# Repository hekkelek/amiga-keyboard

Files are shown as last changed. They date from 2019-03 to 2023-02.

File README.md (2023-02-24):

# Mechanical Replacement Keyboard for Amiga 500 and 1200

Many years ago I got an Amiga 500 with missing keyboard. Since then original keyboards became so expensive, that custom mechanical keyboards can be built for the price of an original.
Unfortunately, Amiga-style Cherry MX keycaps are unavailable, so I used DSA profile blank keycaps. As 9 unit space is rare, I used a 7 unit instead.

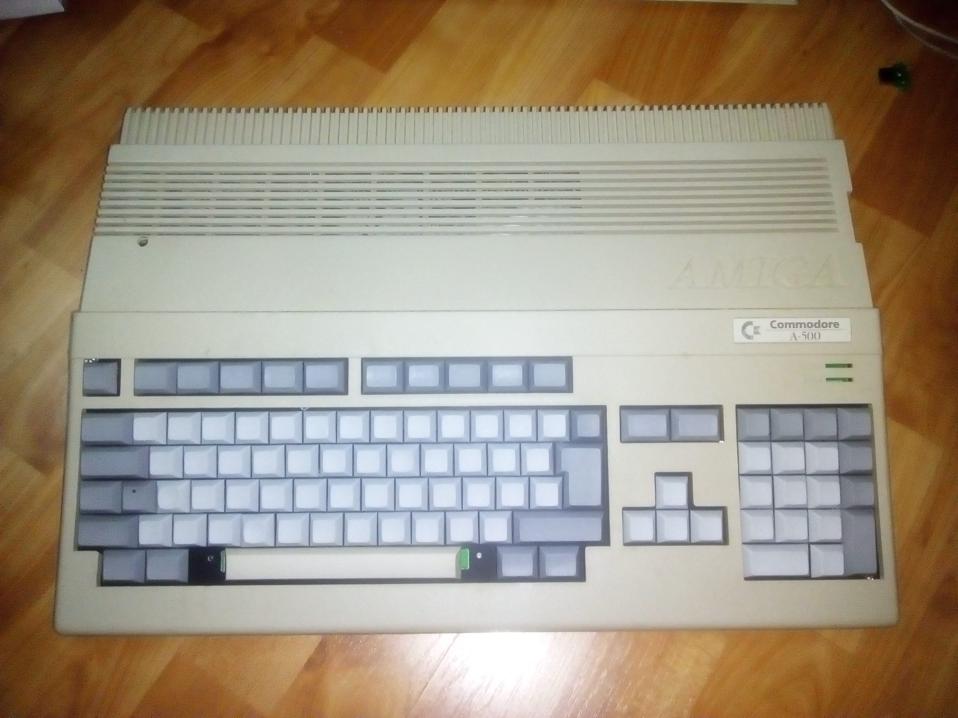
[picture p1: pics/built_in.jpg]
finished


## How to build
First, order the PCB from your favourite manufacturer using the Gerber files in /hw/fab/. At the same time, get a 1.5 mm thick plate, paint it black, and mill out the support plate using a CNC mill. You can find the design files in DXP and Gerber format in /hw/fab/. 
After you got the PCB, populate the connector to the motherboard, and all the SMD components on the top layer. Then, using screws and nuts/washers fasten the support plate to the PCB. Don't forget to add the brackets to larger keys such as space. Only at this point you should solder the key switches. Populate the diodes at the bottom layer. And finally, using an ST-Link v2 programmer, you can burn the hex file in /fw/release/ to the microcontroller.

## Known bugs

Revision A was a failure, as the position of many keys was inaccurate. Revision B seems good so far -- maybe a little bit of fileing needed here and there, for the best fit. Also, the positions of the LEDs are not accurate for the original LEDs.

The firmware is not finished yet -- it works for most of the time, but it's not perfect.

## Tools used

* Altium Designer 2011
* IAR Embedded Workbench for STM8 1.40.1

## Some more pictures
The PCB:
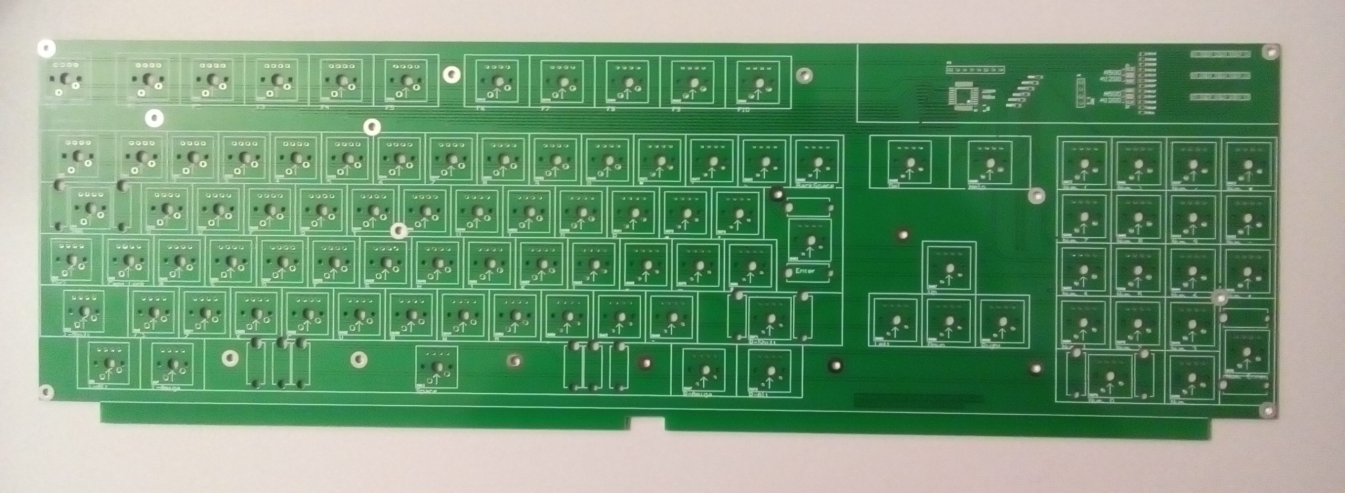
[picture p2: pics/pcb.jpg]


Assembled (note: an additional hole was cut on the plate to debug the MCU):
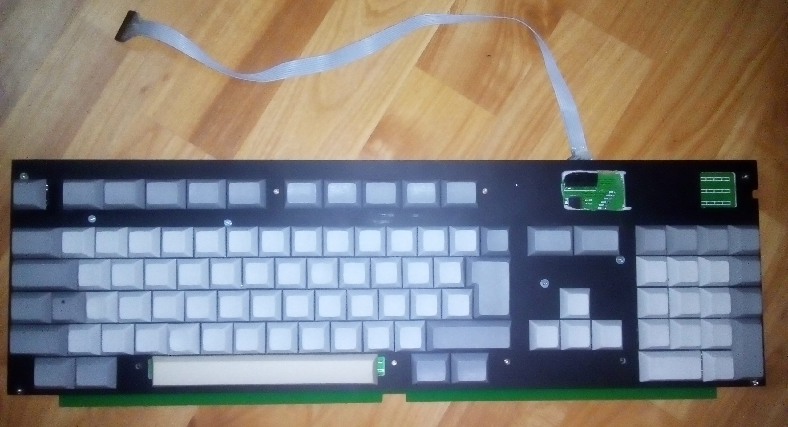
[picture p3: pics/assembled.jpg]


Original Amiga profile keycaps:
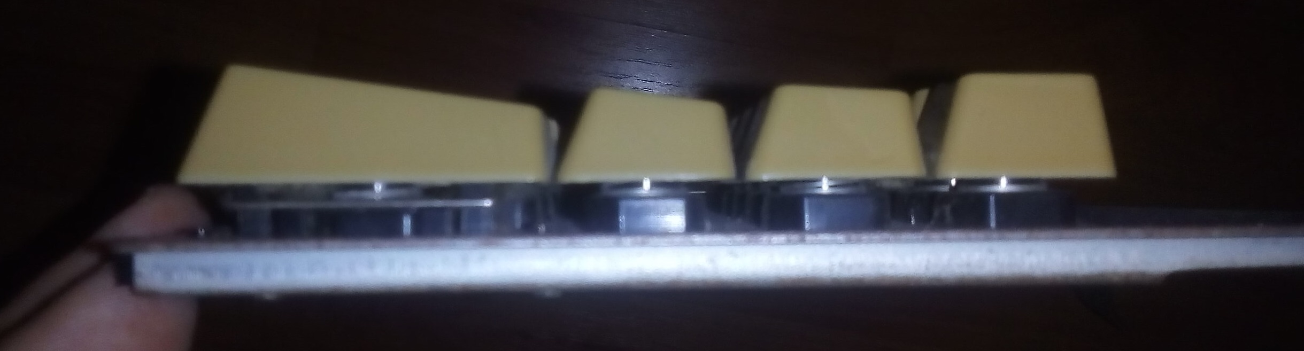
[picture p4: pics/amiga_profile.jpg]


DSA profile keycaps:
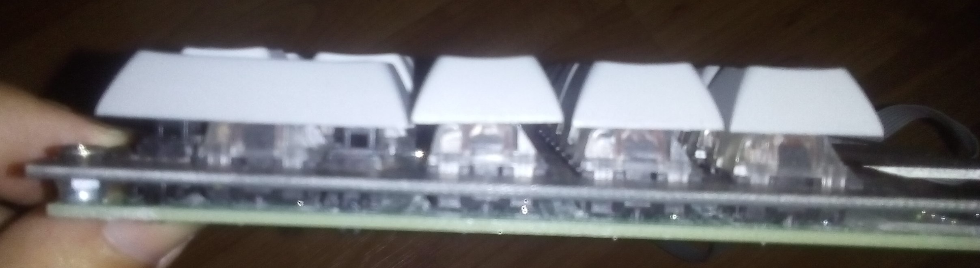
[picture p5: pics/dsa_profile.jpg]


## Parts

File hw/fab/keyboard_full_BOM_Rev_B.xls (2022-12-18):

Designator | Value | Comment | Description | Footprint | Quantity
C1 | 1uF | 0805 | Capacitor SMD Cer X7R 0805 | CAPC2012X135N | 1
C2 | 100nF | 0805 | Capacitor SMD Cer X7R 0805 | CAPC2012X135N | 1
D1, D4, D7, D10 |  | GREEN | Typical LED | LEDSQ_5mm | 4
D2, D3, D5, D6, D8, D9, D11, D12 |  | YELLOW | Typical LED | LEDSQ_5mm | 8
D13, D14, D15, D16, D17, D18, D19, D20, D21, D22, D23, D24, D25, D26, D27, D28, D29, D30, D31, D32, D33, D34, D35, D36, D37, D38, D39, D40, D41, D42, D43, D44, D45, D46, D47, D48, D49, D50, D51, D52, D53, D54, D55, D56, D57, D58, D59, D60, D61, D62, D63, D64, D65, D66, D67, D68, D69, D70, D71, D72, D73, D74, D75, D76, D77, D78, D79, D80, D81, D82, D83, D84, D85, D86, D87, D88, D89, D90, D91, D92, D93, D94, D95, D96, D97, D98, D99, D100, D101, D102, D103, D104, D105, D106, D107, D108 | Vf=1V @ 10mA | Mini MELF | Diode SMD 100V 150mA 500mW SOD80 | SOD80, LL-34 | 96
P1 |  | SWIM | Header, 4-Pin | HDR1X4 | 1
P2 |  | Amiga Keyboard | Header, 8-Pin | HDR1X8 | 1
R1, R2, R3, R4, R5, R6, R7, R8, R10, R11, R12, R13, R14, R15, R16, R17, R18, R19, R20, R21, R22, R23, R24, R25, R26, R27, R28, R29, R30, R31, R32, R33, R34, R35, R36, R37, R38, R39, R40, R41, R42, R43, R44, R45, R46, R47, R48, R49, R50, R51, R52, R53, R54, R55, R56, R57, R58, R59, R60, R61, R62, R63, R64, R65, R66, R67, R68, R69, R70, R71, R72, R73, R74, R75, R76, R77, R78, R79, R80, R81, R82, R83, R84, R85, R86, R87, R88, R89, R90, R91, R92, R93, R94, R95, R96 | Opc. | 0805 | Resistor SMD chip 0.0 Ohm 0.125W 0805 | RESC2012N_ZERO | 95
R9, R97 | 1k | 0805 | Resistor SMD chip 0.0 Ohm 0.125W 0805 | RESC2012N_ZERO | 2
R98, R99, R100, R101, R102, R103 | 4,7k | 0805 | Resistor SMD chip 0.0 Ohm 0.125W 0805 | RESC2012N_ZERO | 6
R104, R105, R106, R107, R108, R109, R110, R111, R112, R113, R114, R115 | TBD | 0805 | Resistor SMD chip 0.0 Ohm 0.125W 0805 | RESC2012N_ZERO | 12
ST1, ST2, ST3, ST4, ST5, ST6, ST7, ST8, ST9, ST10, ST11, ST12, ST13, ST14, ST15, ST16 |  | Cherry MX Stabilizer | Stabilizer for Cherry MX compatible switches | CHERRYMX_STAB | 16
SW1 |  | L-Alt | Cherry MX keyboard switch | CHERRYMX_5PIN | 1
SW2 |  | L-Shift | Cherry MX keyboard switch | CHERRYMX_5PIN | 1
SW3 |  | Ctrl | Cherry MX keyboard switch | CHERRYMX_5PIN | 1
SW4 |  | TAB | Cherry MX keyboard switch | CHERRYMX_5PIN | 1
SW5 |  | ~ | Cherry MX keyboard switch | CHERRYMX_5PIN | 1
SW6 |  | ESC | Cherry MX keyboard switch | CHERRYMX_5PIN | 1
SW7 |  | L-Amiga | Cherry MX keyboard switch | CHERRYMX_5PIN | 1
SW8 |  | < > | Cherry MX keyboard switch | CHERRYMX_5PIN | 1
SW9 |  | Caps Lock | Cherry MX keyboard switch | CHERRYMX_5PIN | 1
SW10 |  | Q | Cherry MX keyboard switch | CHERRYMX_5PIN | 1
SW11 |  | 1 | Cherry MX keyboard switch | CHERRYMX_5PIN | 1
SW12 |  | F1 | Cherry MX keyboard switch | CHERRYMX_5PIN | 1
SW13 |  | Space | Cherry MX keyboard switch | CHERRYMX_5PIN | 1
SW14 |  | Z | Cherry MX keyboard switch | CHERRYMX_5PIN | 1
SW15 |  | A | Cherry MX keyboard switch | CHERRYMX_5PIN | 1
SW16 |  | W | Cherry MX keyboard switch | CHERRYMX_5PIN | 1
SW17 |  | 2 | Cherry MX keyboard switch | CHERRYMX_5PIN | 1
SW18 |  | F2 | Cherry MX keyboard switch | CHERRYMX_5PIN | 1
SW19 |  | Num. * | Cherry MX keyboard switch | CHERRYMX_5PIN | 1
SW20 |  | X | Cherry MX keyboard switch | CHERRYMX_5PIN | 1
SW21 |  | S | Cherry MX keyboard switch | CHERRYMX_5PIN | 1
SW22 |  | E | Cherry MX keyboard switch | CHERRYMX_5PIN | 1
SW23 |  | 3 | Cherry MX keyboard switch | CHERRYMX_5PIN | 1
SW24 |  | F3 | Cherry MX keyboard switch | CHERRYMX_5PIN | 1
SW25 |  | Num. - | Cherry MX keyboard switch | CHERRYMX_5PIN | 1
SW26 |  | C | Cherry MX keyboard switch | CHERRYMX_5PIN | 1
SW27 |  | D | Cherry MX keyboard switch | CHERRYMX_5PIN | 1
SW28 |  | R | Cherry MX keyboard switch | CHERRYMX_5PIN | 1
SW29 |  | 4 | Cherry MX keyboard switch | CHERRYMX_5PIN | 1
SW30 |  | F4 | Cherry MX keyboard switch | CHERRYMX_5PIN | 1
SW31 |  | Num. Enter | Cherry MX keyboard switch | CHERRYMX_5PIN | 1
SW32 |  | V | Cherry MX keyboard switch | CHERRYMX_5PIN | 1
SW33 |  | F | Cherry MX keyboard switch | CHERRYMX_5PIN | 1
SW34 |  | T | Cherry MX keyboard switch | CHERRYMX_5PIN | 1
SW35 |  | 5 | Cherry MX keyboard switch | CHERRYMX_5PIN | 1
SW36 |  | F5 | Cherry MX keyboard switch | CHERRYMX_5PIN | 1
SW37 |  | Num. / | Cherry MX keyboard switch | CHERRYMX_5PIN | 1
SW38 |  | B | Cherry MX keyboard switch | CHERRYMX_5PIN | 1
SW39 |  | G | Cherry MX keyboard switch | CHERRYMX_5PIN | 1
SW40 |  | Y | Cherry MX keyboard switch | CHERRYMX_5PIN | 1
SW41 |  | 6 | Cherry MX keyboard switch | CHERRYMX_5PIN | 1
SW42 |  | F6 | Cherry MX keyboard switch | CHERRYMX_5PIN | 1
SW43 |  | Num. 9 | Cherry MX keyboard switch | CHERRYMX_5PIN | 1
SW44 |  | N | Cherry MX keyboard switch | CHERRYMX_5PIN | 1
SW45 |  | H | Cherry MX keyboard switch | CHERRYMX_5PIN | 1
SW46 |  | U | Cherry MX keyboard switch | CHERRYMX_5PIN | 1
SW47 |  | 7 | Cherry MX keyboard switch | CHERRYMX_5PIN | 1
SW48 |  | F7 | Cherry MX keyboard switch | CHERRYMX_5PIN | 1
SW49 |  | Num. 3 | Cherry MX keyboard switch | CHERRYMX_5PIN | 1
SW50 |  | M | Cherry MX keyboard switch | CHERRYMX_5PIN | 1
SW51 |  | J | Cherry MX keyboard switch | CHERRYMX_5PIN | 1
SW52 |  | I | Cherry MX keyboard switch | CHERRYMX_5PIN | 1
SW53 |  | 8 | Cherry MX keyboard switch | CHERRYMX_5PIN | 1
SW54 |  | F8 | Cherry MX keyboard switch | CHERRYMX_5PIN | 1
SW55 |  | Num. . | Cherry MX keyboard switch | CHERRYMX_5PIN | 1
SW56 |  | , | Cherry MX keyboard switch | CHERRYMX_5PIN | 1
SW57 |  | K | Cherry MX keyboard switch | CHERRYMX_5PIN | 1
SW58 |  | O | Cherry MX keyboard switch | CHERRYMX_5PIN | 1
SW59 |  | 9 | Cherry MX keyboard switch | CHERRYMX_5PIN | 1
SW60 |  | F9 | Cherry MX keyboard switch | CHERRYMX_5PIN | 1
SW61 |  | Num. ) | Cherry MX keyboard switch | CHERRYMX_5PIN | 1
SW62 |  | . | Cherry MX keyboard switch | CHERRYMX_5PIN | 1
SW63 |  | L | Cherry MX keyboard switch | CHERRYMX_5PIN | 1
SW64 |  | P | Cherry MX keyboard switch | CHERRYMX_5PIN | 1
SW65 |  | 0 | Cherry MX keyboard switch | CHERRYMX_5PIN | 1
SW66 |  | F10 | Cherry MX keyboard switch | CHERRYMX_5PIN | 1
SW67 |  | R-Amiga | Cherry MX keyboard switch | CHERRYMX_5PIN | 1
SW68 |  | - | Cherry MX keyboard switch | CHERRYMX_5PIN | 1
SW69 |  | Ö | Cherry MX keyboard switch | CHERRYMX_5PIN | 1
SW70 |  | Ü | Cherry MX keyboard switch | CHERRYMX_5PIN | 1
SW71 |  | ß | Cherry MX keyboard switch | CHERRYMX_5PIN | 1
SW72 |  | Num. ( | Cherry MX keyboard switch | CHERRYMX_5PIN | 1
SW73 |  | R-Alt | Cherry MX keyboard switch | CHERRYMX_5PIN | 1
SW74 |  | R-Shift | Cherry MX keyboard switch | CHERRYMX_5PIN | 1
SW75 |  | Ä | Cherry MX keyboard switch | CHERRYMX_5PIN | 1
SW76 |  | + | Cherry MX keyboard switch | CHERRYMX_5PIN | 1
SW77 |  | ' | Cherry MX keyboard switch | CHERRYMX_5PIN | 1
SW78 |  | Num. 2 | Cherry MX keyboard switch | CHERRYMX_5PIN | 1
SW79 |  | Num. 0 | Cherry MX keyboard switch | CHERRYMX_5PIN | 1
SW80 |  | Left | Cherry MX keyboard switch | CHERRYMX_5PIN | 1
SW81 |  | # | Cherry MX keyboard switch | CHERRYMX_5PIN | 1
SW82 |  | Enter | Cherry MX keyboard switch | CHERRYMX_5PIN | 1
SW83 |  | \ | Cherry MX keyboard switch | CHERRYMX_5PIN | 1
SW84 |  | Num. 1 | Cherry MX keyboard switch | CHERRYMX_5PIN | 1
SW85 |  | Num. 8 | Cherry MX keyboard switch | CHERRYMX_5PIN | 1
SW86 |  | Down | Cherry MX keyboard switch | CHERRYMX_5PIN | 1
SW87 |  | Up | Cherry MX keyboard switch | CHERRYMX_5PIN | 1
SW88 |  | Help | Cherry MX keyboard switch | CHERRYMX_5PIN | 1
SW89 |  | BackSpace | Cherry MX keyboard switch | CHERRYMX_5PIN | 1
SW90 |  | Num. 7 | Cherry MX keyboard switch | CHERRYMX_5PIN | 1
SW91 |  | Num. + | Cherry MX keyboard switch | CHERRYMX_5PIN | 1
SW92 |  | Right | Cherry MX keyboard switch | CHERRYMX_5PIN | 1
SW93 |  | Num. 4 | Cherry MX keyboard switch | CHERRYMX_5PIN | 1
SW94 |  | Num. 6 | Cherry MX keyboard switch | CHERRYMX_5PIN | 1
SW95 |  | Del | Cherry MX keyboard switch | CHERRYMX_5PIN | 1
SW96 |  | Num. 5 | Cherry MX keyboard switch | CHERRYMX_5PIN | 1
U1 |  | STM8S003K3 | ST Microelectronics STM8S003K3 microcontroller | LQFP32_M | 1

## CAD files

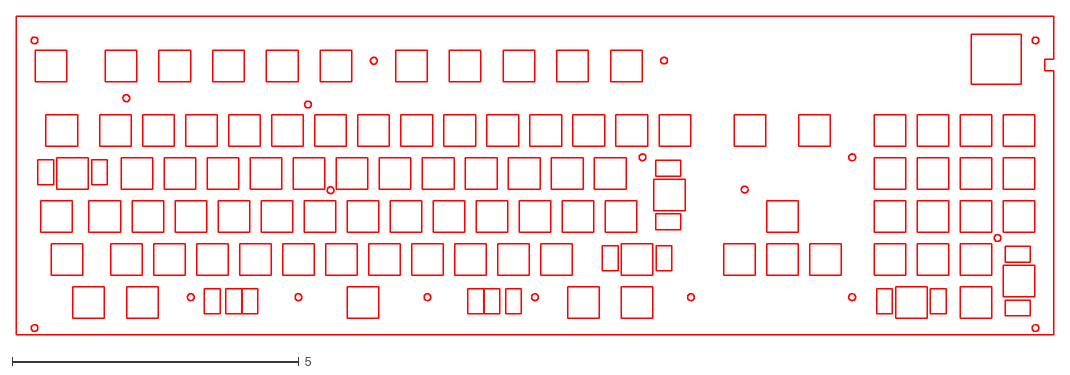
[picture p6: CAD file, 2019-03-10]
hw/fab/keyboard_full_plate_Rev_B.dxf
18.1 x 5.55

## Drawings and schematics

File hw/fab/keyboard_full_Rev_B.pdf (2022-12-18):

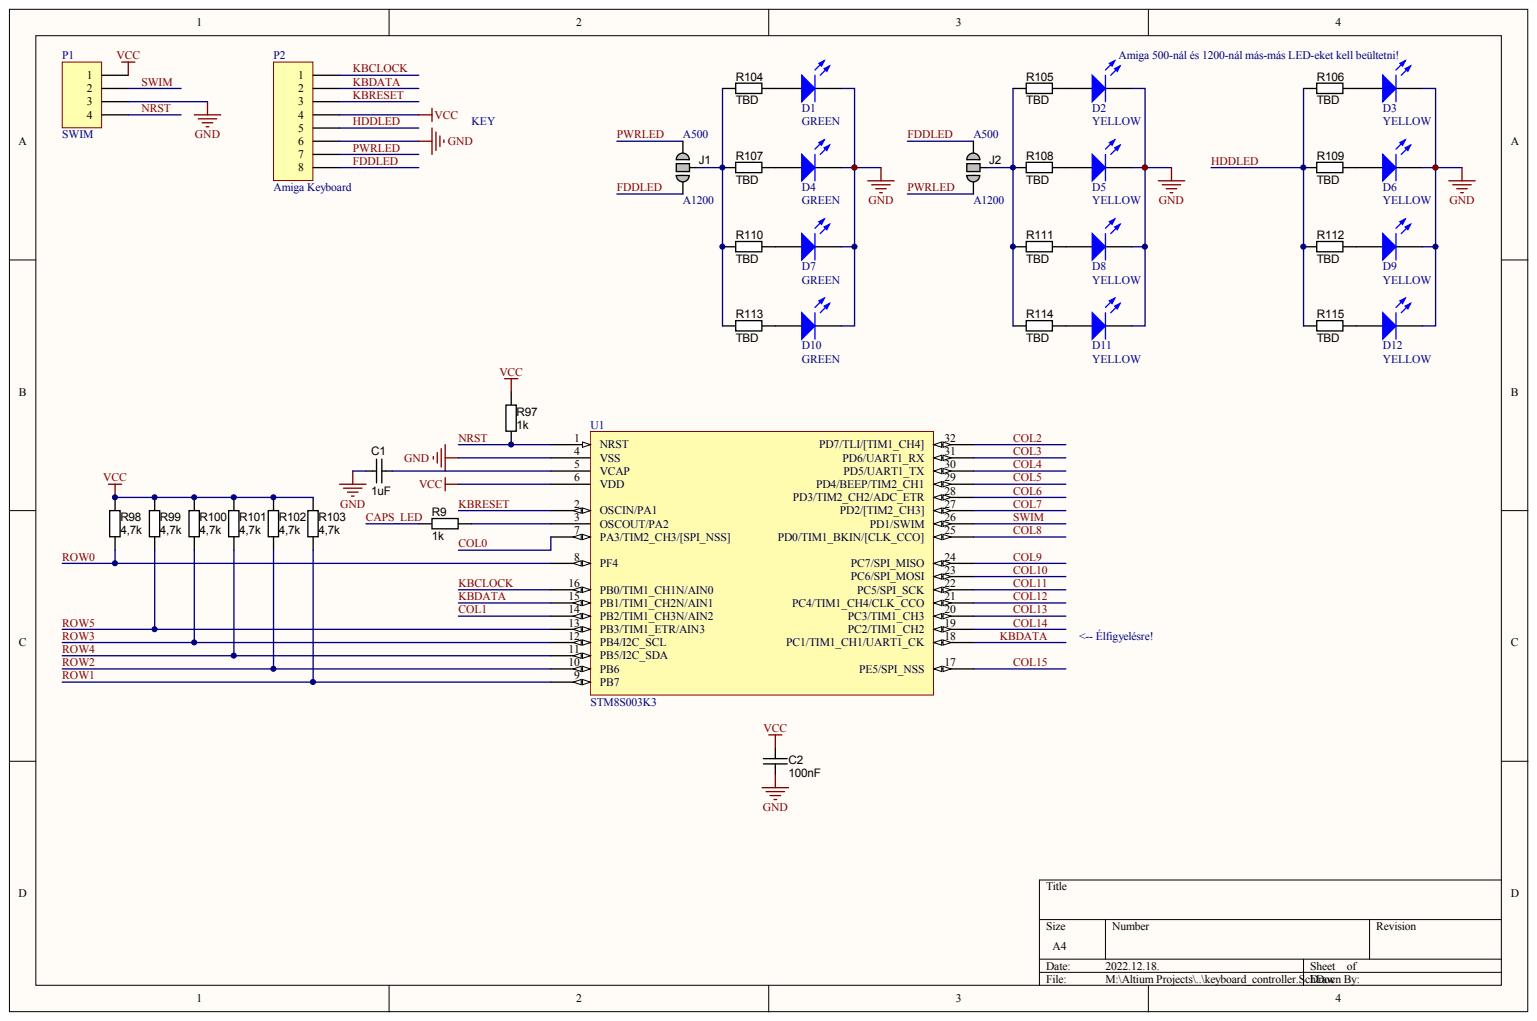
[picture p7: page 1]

Amiga 500-nál és 1200-nál más-más LED-eket kell beültetni!

PA3/TIM2_CH3/[SPI_NSS] 7

KBCLOCK

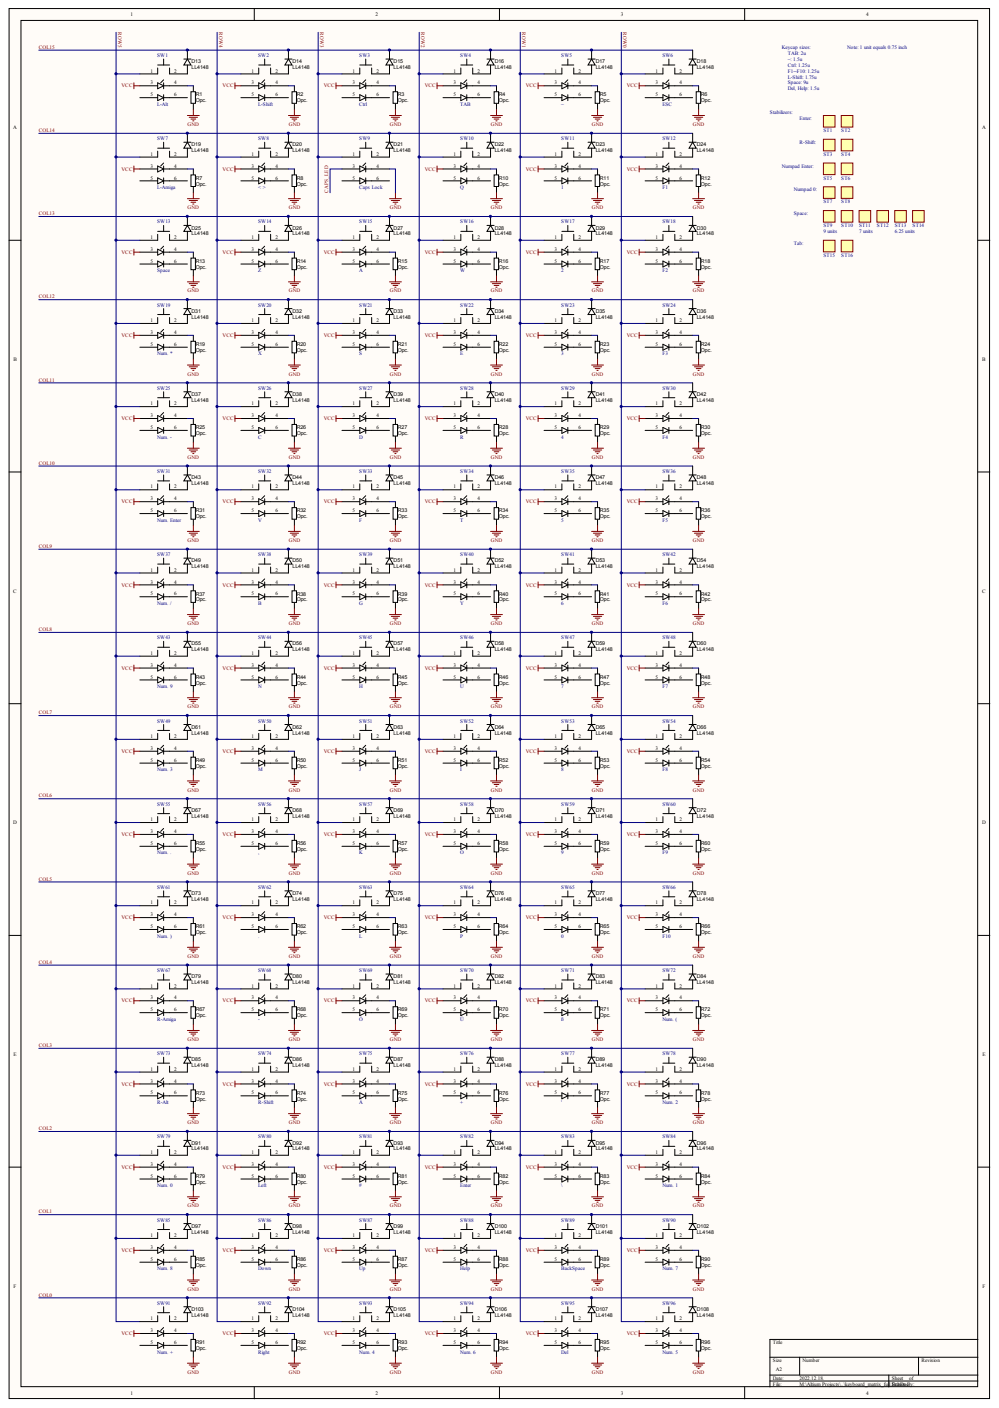
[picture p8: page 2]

Note: 1 unit equals 0.75 inch

Date: 2022.12.18. | Sheet of

1 2 3 | File: M:\Altium Projects\..\keyboard_matrix_full.DScrahwnDocBy: 4

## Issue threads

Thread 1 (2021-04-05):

OEM profile keycaps with dysub printing

OleUrgast, 2021-04-05:
Not a real issue, more an idea for the keycaps:
On https://youtu.be/-scV7LLvdh8 you find a video how to print yourself onto keycaps with dysub. As you already put so much work into your project, you might also print to the keycaps. As most printshops already have a printer to print on dysub transfer paper, you need only to make that simple press.
Also there is a keycap designer for cherry keycaps on thingiverse. https://www.thingiverse.com/thing:2783650
The ISO enter generation does not work correctly, but all other keys work fine, even the 1.5 R5 OEM (function keys). ISO Enter in OEM should be easy to get elsethere. So with a resin printer you should be able to make all keycaps yourself.

hekkelek, 2021-04-06:
Thank you for the suggestion. When I'll have time, I'll definitely try the dye sublimation method. As for the keycaps, I've already printed a 9-unit spacebar using the linked library. I'll upload it sometime.

vejinnovem, 2023-01-07:
I already designed all keys for Amiga with proper sizes (the enormous space as well) but I need to print all of them first before I share them here (and I'll do it with pleasure).

vejinnovem, 2023-02-24:
@hekkelek Do you own any 3d model of the bracket to mount the PCB? I don't own any stock one, so I have to put PCB loosely on the case. On the pictures it looks like you have some custom bracket. I write it here since it's also 3d-themed issue.
I'm printing both resin and filament versions of keycaps, so expect something more soon.

hekkelek, 2023-02-24:
@vejinnovem It's not a 3D printed bracket, but a plate. I've milled it from a 1.6 mm thick PCB using a CNC mill. You can find the design in DXP and Gerber formats in /hw/fab/ as keyboard_full_plate_Rev_B.dxf and keyboard_full_plate_Rev_B.GM4, respectively.

vejinnovem, 2023-03-12:
@hekkelek you think you could somehow convert it to a 3d object or at least svg?

hekkelek, 2023-03-12:
@vejinnovem It can not be converted into a 3d objects, because it's a 2D drawing. DXF and Gerber are already CAD software compatible files. Use a tool that can handle them.
I've added an SVG render, but I discourage to use it, because in general, SVGs do not contain information about the size.

vejinnovem, 2023-03-12:
don't worry, I'll scale it to proper size using calipers and measuring the distance between the holes in real PCB :) Thanks a lot!
By the way, the keys are almost ready:
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
Just need to fix few of the models to have the full set and I'll be ready to share it!

vejinnovem, 2023-06-01:
@hekkelek Are you able to tell me what are the dimensions of the PCB I asked you for SVG of?

hekkelek, 2023-06-02:
@vejinnovem Yes, the outer dimensions of the plate are 459.581 mm x 141.089 mm (18093.75 mil x 5554.688 mil).

vejinnovem, 2023-06-08:
https://www.thingiverse.com/thing:6067745
there it is, you can add it to your project if you want. Feel free to comment it, I'm not sure If I did anything good. I printed parts of the SVG but somehow the keyboard seems to sit too high. I have to figure it out.

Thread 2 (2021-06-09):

Firmware status?

gadyke, 2021-06-09:
Forgive me, as this isn't quite an "issue" but it's the easiest way I can find to get in touch.

You mention in passing in your README that the firmware for the STM isn't quite perfect but generally works. Can you comment on any of the issues it has? I'm seriously looking at building one of these boards as part of a wider 500+ replica build (so therefore also replacing the mitsumi controller too), but it'd be good to know if it's 99% perfect or more like 50%...

Thanks!

Greg

hekkelek, 2021-06-09:
Currently, it works, but I'm not entirely sure about the timings. So expect that it's not 100% timing accurate. But so far, I didn't encounter any serious problems. So I would say it's more like 99% perfect.

The only known issue it has is the reset handling (Ctrl+LAmiga+RAmiga). According to the protocol description, Amiga keyboards should send a special message to the motherboard before the reset line being pulled and in certain circumstances, the OS can tell the keyboard to wait a few seconds before pulling the reset line. This is not implemented as per today.

But of course, if you encounter any errors, I'll happily help to debug and fix it, provided you use the same MCU and pinout.

gadyke, 2021-06-09:
That's really helpful thank you!

This is a different topic so apologies for stretching the use of the issue system further still. Looking at the switch mounts on the board I'm a little confused as to which type of Cherry switch is intended, or whether it's designed to be able to accept any type of switch by including all four possible pin positions for each key.

By default I would normally go for something like [this](https://www.mouser.co.uk/ProductDetail/540-MX1A-11NW), with no diode and no LED. Can you share the precise model you ended up using?

Thanks again,

Greg

hekkelek, 2021-06-09:
Any type of "Cherry MX compatible" switch should fit. In my prototype I used the PCB-mounted (5-pin) version of Gateron Browns. They fit, but since Gateron is known to use a little bigger fixation pins, a bit of force should be applied when assembling. The one you linked should fit perfectly.

The LEDs are entirely optional even in original Cherry MX switches (except for caps lock). Diodes are placed at the bottom of the PCB, so you don't need switches that have integrated diodes.

HeathenUK, 2021-06-09:
Hopefully a final question for now - have I read the schematic right, are the resistors on each key switch 0 Ohm?

G

hekkelek, 2021-06-09:
No, they're marked as optional. If you want LEDs, you'll need to choose a resistor value appropriate for that specific LED. The only exception is the caps lock LED, where I used a 1 kOhm resistor (R9) -- compatible with most red LEDs.

hekkelek, 2021-06-09:
So "Opc." on the schematic means optional.

Closed 2021-06-15.

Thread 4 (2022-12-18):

BOM?

vejinnovem, 2022-12-18:
Hello, it seems I can't find any BOM for this project.
A friend of mine ordered a PCB for me and I already have all mx switches soldered in but I can't find, what kind of resistors, diodes or capacitors should I order.

hekkelek, 2022-12-18:
Hi!
I've added the schematic export and the BOM to the hw/fab/ directory.
The Power/FDD/HDD LEDs need some experimenting and probably their pins need to be bended before soldering. This is why resistors R104--R115 have no specified values yet, but fitting 1kOhms resistors would work fine.
There are optional resistors (marked by "Opc.") under the key switches if you want backlit keys. The resistor values should be chosen depending on the LED colors you choose.

vejinnovem, 2022-12-18:
Oh man, thanks so much for the... sudden response!

hekkelek, 2022-12-18:
You're welcome. If you have any questions, feel free to ask.

Closed 2022-12-18.

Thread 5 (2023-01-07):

ROW0 shorted together?

vejinnovem, 2023-01-07:
I finally made it work. Every single key works as intented, except for the ROW0. (ESC, F1-F10, NUM-left-bracket, NUM7, NUM5, NUM1, NUM2).
No matter what key from this row I press, every other keys are pressed together. It doesn't seem to be too much solder anywhere.
The diodes are correct, the resistor on this row is nowhere shorted and every part keeps the same resistance to ground as the other, working parts.
Maybe you may enlighten me, where else can I look?
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

hekkelek, 2023-01-07:
Sounds like your resistor R98 is not soldered properly, has incorrect value, or is defective. The reason why I think that is that without a pullup resistor the ROW0 line will stay low for a long time (after all, long wires on a PCB have significant capacitance), and so the software will read 0 from ROW0 for all COL0...15 combinations.

Can you send me a photo about your R98?

vejinnovem, 2023-01-07:
I tried taking a photo of it but it would be not crystal-clear anyway, so I just resoldered the resistor.
Seems like it wasn't connected properly to the row (it's actually my first attempt with any smd soldering, using regular solder-iron instead of hot-air solution.
Now all of the keys work. Thank you, the issue is resolved.
You're the man!

hekkelek, 2023-01-07:
Great! Have fun using it :)

Closed 2023-01-07.

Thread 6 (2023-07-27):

CPL File

gotnull, 2023-07-27:
Is it possible to include a CPL file that includes the correct rotation and placement of each component? This is required by PCBWay to assemble and print.

hekkelek, 2023-07-27:
I've added the CPL file. Keep in mind that there are differences between PCB manufacturers and sometimes the orientation is different for components depending on if they are packed in reel or tray. So the orientations should be checked and modified if required.

Also, I don't recommend printing the support plate for the keyboard -- it just does not hold up well. Instead, I recommend to CNC mill it from 1.5 mm FR4 epoxy plate.

gotnull, 2023-07-27:
Thanks so much for doing that. I did come across the following mechanical keyboard option for the A500 here although they don’t offer a CPL file and after reaching out I haven’t yet heard a response.

https://github.com/HenrykRichter/A500KB/tree/main/PCB

Would it at all be possible to generate a CPL for this as well?

hekkelek, 2023-07-27:
That project is designed using KiCAD. Different software. And although it is possible to export the pick & place files, I won't do it because it's not my project. BTW you can find lots of resources about KiCAD, and as it is a free and open source software, you can do it yourself too.

Closed 2023-07-27.

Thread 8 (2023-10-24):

distance nuts between the PCB and the plate

vejinnovem, 2023-10-24:
Hello,
I recently saw that you have some nuts between the keyboard PCB and the plate that we talked about some time ago.
I haven't seen it before and thus I thought that there's something wrong with my 3d print of the plate that was supposed to reinforce the PCB.
Could you tell me what are the dimensions of that nuts so the plate could sit properly on the PCB?
You did a great work with that keyboard! Cheers!

hekkelek, 2023-10-24:
Hi!
For spacers I've used M3 size DIN 985 prevailing torque nuts. Their heights are between 3.7 and 4 mm by standard. Actually, I think it would be better to 3D print some spacers, that are 3.4 mm tall, as the height of the spacer + the height of the plate should be 5 mm.
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

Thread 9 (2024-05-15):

Issues Programming the Microcontroller

HardwareHuligan, 2024-05-15:
hello I'm having issues  programing  the STM8S003K3T6C  in StM32CubeProgrammer or Stm32 St link utility   same error "no stm32 target found "  . sorry total noob here  any help with how to hex flash would be greatly appreciated   -
Thanks  !

hekkelek, 2024-05-15:
Hi! Well, the problem is you tried to program an STM8 using an STM32 programmer software. Two totally different microcontrollers. I'd suggest to use ST Visual Programmer (see https://www.st.com/en/development-tools/stvp-stm8.html ) for flashing the hex file.

HardwareHuligan, 2024-05-16:
Thanks and sorry totally new  to all this  - Love your keyboard  again THANK YOU

Closed 2024-05-15.

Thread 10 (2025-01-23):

Question on keyboard

N4CNR, 2025-01-23:
do you know of anyone making this keyboard to work like a normal keyboard. ? want to put a unit in a 500 case but need keyboard for it that works with any arm64 board

hekkelek, 2025-01-23:
Well, the microcontroller used on this keyboard has no USB peripherial (which would be important to interface it with an Arm SBC), so it can not be done with just a firmware update.

A possible solution is a device which "translates" the Amiga keyboard protocol to USB-HID. Using a quick google search I've found this: https://github.com/tkoecker/amigakb
If you build it make sure to use the pin header (in the correct direction!) to connect this (or an original) Amiga keyboard to the adapter board.

Closed 2025-01-23.

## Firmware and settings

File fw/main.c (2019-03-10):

/**
  ******************************************************************************
  * @file    Project/main.c 
  * @author  MCD Application Team
  * @version V2.2.0
  * @date    30-September-2014
  * @brief   Main program body
   ******************************************************************************
  * @attention
  *
  * <h2><center>&copy; COPYRIGHT 2014 STMicroelectronics</center></h2>
  *
  * Licensed under MCD-ST Liberty SW License Agreement V2, (the "License");
  * You may not use this file except in compliance with the License.
  * You may obtain a copy of the License at:
  *
  *        http://www.st.com/software_license_agreement_liberty_v2
  *
  * Unless required by applicable law or agreed to in writing, software 
  * distributed under the License is distributed on an "AS IS" BASIS, 
  * WITHOUT WARRANTIES OR CONDITIONS OF ANY KIND, either express or implied.
  * See the License for the specific language governing permissions and
  * limitations under the License.
  *
  ******************************************************************************
  */ 


/* Includes ------------------------------------------------------------------*/
#include <intrinsics.h>
#include "stm8s.h"
#include "stm8s_gpio.h"
#include "stm8s_spi.h"
#include "stm8s_tim2.h"

#include "types.h"
#include "delay.h"
#include "matrix.h"
#include "amiga_key.h"

/* Private defines -----------------------------------------------------------*/
#define  F_CPU        16000000u

#if !defined(F_CPU)
#error F_CPU is not defined!
#endif

/* Private function prototypes -----------------------------------------------*/

/* Private functions ---------------------------------------------------------*/

void main(void)
{
  // Clock init -- after reset, internal 2 MHz is configured as CPU clock
  CLK_SYSCLKConfig( CLK_PRESCALER_HSIDIV1 );  // this is needed for 16 MHz CPU clock
  CLK_ClockSwitchConfig( CLK_SWITCHMODE_MANUAL, CLK_SOURCE_HSI, DISABLE, CLK_CURRENTCLOCKSTATE_DISABLE );
  
  //TODO: selftests --  flash CRC, watchdog, timers, etc.
  
  Matrix_Init();
  AmigaKey_Init();
  
  // Timer 2 init -- this will be used for sampling the keys
  TIM2_TimeBaseInit( TIM2_PRESCALER_1, 5000u );  //TODO: az 5000u a 16 MHz-es órajelből, az 5 ms prellegési időből és a 16 oszlopból (column) jön ki. A konstansokból kéretik számolni!
  TIM2_ITConfig( TIM2_IT_UPDATE, ENABLE );
  TIM2_Cmd( ENABLE );
  
  enableInterrupts();
  
  /* Main cycle */
  while( TRUE )
  {
    Matrix_Cycle();
    AmigaKey_Cycle();
  }
}


#ifdef USE_FULL_ASSERT

/**
  * @brief  Reports the name of the source file and the source line number
  *   where the assert_param error has occurred.
  * @param file: pointer to the source file name
  * @param line: assert_param error line source number
  * @retval : None
  */
void assert_failed(u8* file, u32 line)
{ 
  /* User can add his own implementation to report the file name and line number,
     ex: printf("Wrong parameters value: file %s on line %d\r\n", file, line) */

  /* Infinite loop */
  while( 1 )
  {
  }
}
#endif


/************************ (C) COPYRIGHT STMicroelectronics *****END OF FILE****/

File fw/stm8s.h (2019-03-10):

/**
  ******************************************************************************
  * @file    stm8s.h
  * @author  MCD Application Team
  * @version V2.2.0
  * @date    30-September-2014
  * @brief   This file contains all HW registers definitions and memory mapping.
   ******************************************************************************
  * @attention
  *
  * <h2><center>&copy; COPYRIGHT 2014 STMicroelectronics</center></h2>
  *
  * Licensed under MCD-ST Liberty SW License Agreement V2, (the "License");
  * You may not use this file except in compliance with the License.
  * You may obtain a copy of the License at:
  *
  *        http://www.st.com/software_license_agreement_liberty_v2
  *
  * Unless required by applicable law or agreed to in writing, software 
  * distributed under the License is distributed on an "AS IS" BASIS, 
  * WITHOUT WARRANTIES OR CONDITIONS OF ANY KIND, either express or implied.
  * See the License for the specific language governing permissions and
  * limitations under the License.
  *
  ******************************************************************************
  */

#include "types.h"

/* Define to prevent recursive inclusion -------------------------------------*/
#ifndef __STM8S_H
#define __STM8S_H

/** @addtogroup STM8S_StdPeriph_Driver
  * @{
  */
  
/* Uncomment the line below according to the target STM8S or STM8A device used in your
   application. */

 /* #define STM8S208 */      /*!< STM8S High density devices with CAN */
 /* #define STM8S207 */      /*!< STM8S High density devices without CAN */
 /* #define STM8S007 */      /*!< STM8S Value Line High density devices */
 /* #define STM8AF52Ax */    /*!< STM8A High density devices with CAN */
 /* #define STM8AF62Ax */    /*!< STM8A High density devices without CAN */
 /* #define STM8S105 */      /*!< STM8S Medium density devices */
 /* #define STM8S005 */      /*!< STM8S Value Line Medium density devices */
 /* #define STM8AF626x */    /*!< STM8A Medium density devices */
 /* #define STM8AF622x */    /*!< STM8A Low density devices */
 /* #define STM8S103 */      /*!< STM8S Low density devices */
  #define STM8S003       /*!< STM8S Value Line Low density devices */
 /* #define STM8S903 */      /*!< STM8S Low density devices */

/*   Tip: To avoid modifying this file each time you need to switch between these
        devices, you can define the device in your toolchain compiler preprocessor. 

  - High-Density STM8A devices are the STM8AF52xx STM8AF6269/8x/Ax,
    STM8AF51xx, and STM8AF6169/7x/8x/9x/Ax microcontrollers where the Flash memory
    density ranges between 32 to 128 Kbytes
  - Medium-Density STM8A devices are the STM8AF622x/4x, STM8AF6266/68,
    STM8AF612x/4x, and STM8AF6166/68 microcontrollers where the Flash memory 
    density ranges between 8 to 32 Kbytes
  - High-Density STM8S devices are the STM8S207xx, STM8S007 and STM8S208xx microcontrollers
    where the Flash memory density ranges between 32 to 128 Kbytes.
  - Medium-Density STM8S devices are the STM8S105x and STM8S005 microcontrollers
    where the Flash memory density ranges between 16 to 32-Kbytes.
  - Low-Density STM8A devices are the STM8AF622x microcontrollers where the Flash
    density is 8 Kbytes. 
  - Low-Density STM8S devices are the STM8S103xx, STM8S003 and STM8S903xx microcontrollers
    where the Flash density is 8 Kbytes. */

#if !defined (STM8S208) && !defined (STM8S207) && !defined (STM8S105) && \
    !defined (STM8S103) && !defined (STM8S903) && !defined (STM8AF52Ax) && \
    !defined (STM8AF62Ax) && !defined (STM8AF626x) && !defined (STM8S007) && \
    !defined (STM8S003)&& !defined (STM8S005) && !defined (STM8AF622x) 
 #error "Please select first the target STM8S/A device used in your application (in stm8s.h file)"
#endif

/******************************************************************************/
/*                   Library configuration section                            */
/******************************************************************************/
/* Check the used compiler */
#if defined(__CSMC__)
 #define _COSMIC_
#elif defined(__RCST7__)
 #define _RAISONANCE_
#elif defined(__ICCSTM8__)
 #define _IAR_
#else
 #error "Unsupported Compiler!"          /* Compiler defines not found */
#endif

#if !defined  USE_STDPERIPH_DRIVER
/* Comment the line below if you will not use the peripherals drivers.
   In this case, these drivers will not be included and the application code will be
   based on direct access to peripherals registers */
 #define USE_STDPERIPH_DRIVER
#endif

/**
  * @brief  In the following line adjust the value of External High Speed oscillator (HSE)
   used in your application

   Tip: To avoid modifying this file each time you need to use different HSE, you
        can define the HSE value in your toolchain compiler preprocessor.
  */
#if !defined  HSE_Value
 #if defined (STM8S208) || defined (STM8S207) || defined (STM8S007) || defined (STM8AF52Ax) || \
     defined (STM8AF62Ax) || defined (STM8AF622x)
  #define HSE_VALUE ((uint32_t)24000000) /* Value of the External oscillator in Hz*/
 #else
  #define HSE_VALUE ((uint32_t)16000000) /* Value of the External oscillator in Hz*/
 #endif /* STM8S208 || STM8S207 || STM8S007 || STM8AF62Ax || STM8AF52Ax || STM8AF622x */
#endif /* HSE_Value */

/**
  * @brief  Definition of Device on-chip RC oscillator frequencies
  */
#define HSI_VALUE   ((uint32_t)16000000) /*!< Typical Value of the HSI in Hz */
#define LSI_VALUE   ((uint32_t)128000)   /*!< Typical Value of the LSI in Hz */

#ifdef _COSMIC_
 #define FAR  @far
 #define NEAR @near
 #define TINY @tiny
 #define EEPROM @eeprom
 #define CONST  const
#elif defined (_RAISONANCE_) /* __RCST7__ */
 #define FAR  far
 #define NEAR data
 #define TINY page0
 #define EEPROM eeprom
 #define CONST  code
 #if defined (STM8S208) || defined (STM8S207) || defined (STM8S007) || defined (STM8AF52Ax) || \
     defined (STM8AF62Ax)
   /*!< Used with memory Models for code higher than 64K */
  #define MEMCPY fmemcpy
 #else /* STM8S903, STM8S103, STM8S003, STM8S105, STM8AF626x, STM8AF622x */
  /*!< Used with memory Models for code less than 64K */
  #define MEMCPY memcpy
 #endif /* STM8S208 or STM8S207 or STM8S007 or STM8AF62Ax or STM8AF52Ax */ 
#else /*_IAR_*/
 #define FAR  __far
 #define NEAR __near
 #define TINY __tiny
 #define EEPROM __eeprom
 #define CONST  const
#endif /* __CSMC__ */

/* For FLASH routines, select whether pointer will be declared as near (2 bytes,
   to handle code smaller than 64KB) or far (3 bytes, to handle code larger 
   than 64K) */
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

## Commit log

2019-03-10 Initial commit.
    [a1200_keyboard_adapter.PcbDoc, a1200_keyboard_adapter.PrjPcb, a1200_keyboard_adapter.SchDoc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]
2022-12-18 Added schematic PDF and BOM.
    [keyboard_full.PrjPcb, keyboard_full_BOM_Rev_B.xls]
2023-03-12 Added SVG render of the keyboard plate.
2023-07-27 Added pick & place CPL file.
    [Pick Place for keyboard_full_Rev_B.csv]
